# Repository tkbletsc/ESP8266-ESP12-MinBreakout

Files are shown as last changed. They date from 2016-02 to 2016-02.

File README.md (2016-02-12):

# ESP8266-ESP12-MinBreakout
Minimal breakout board for the ESP8266 model ESP12 board

A breakout board for the ESP8266 model ESP12 board, but with a twist. The down-facing header pins are installed with very little protrusion on the top, then some insulation is added (electrical tape), then the ESP12 is SMT soldered on top. This makes this breakout far smaller than the existing ones, and much more breadboard friendly.

Comes in through-hole and SMT flavors. The through-hole flavor rev1 has been successfully fabbed and populated and works perfectly.

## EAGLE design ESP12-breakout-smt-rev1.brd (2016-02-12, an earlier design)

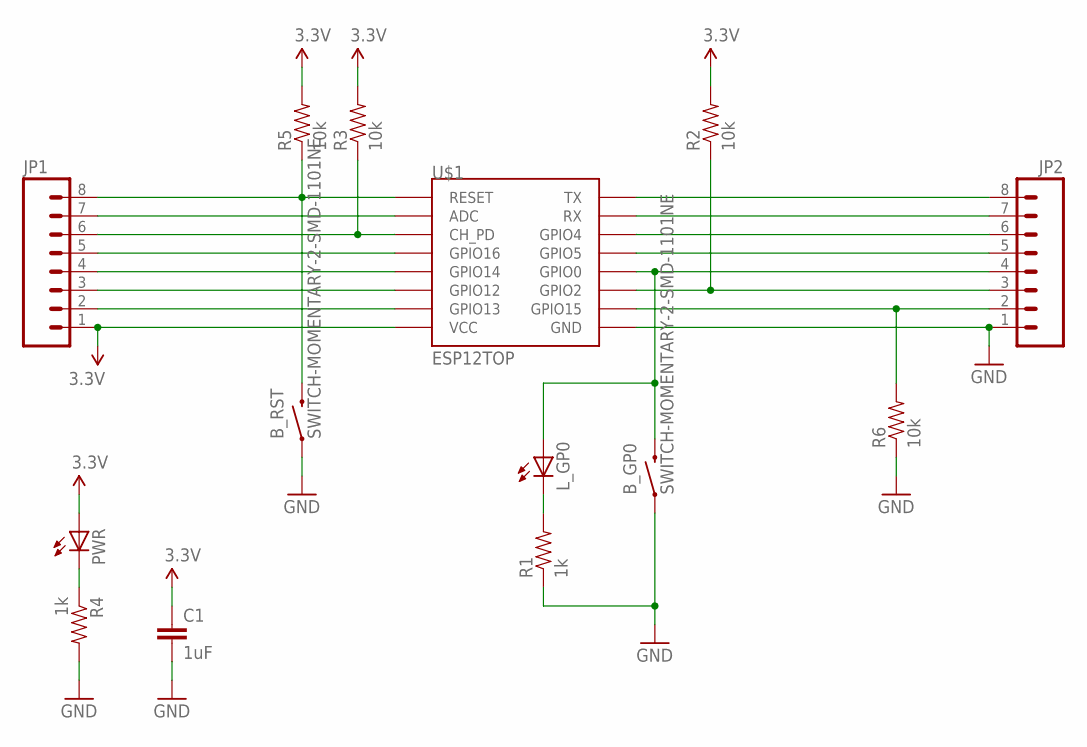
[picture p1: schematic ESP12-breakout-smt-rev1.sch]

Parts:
B_GP0: SWITCH-MOMENTARY-2-SMD-1101NE; TACTILE-SWITCH-1101NE
B_RST: SWITCH-MOMENTARY-2-SMD-1101NE; TACTILE-SWITCH-1101NE
C1: 1uF; 0805
JP1, JP2: M08; 1X08_PIN1_NO_SILK
L_GP0: LEDCHIPLED_0805; CHIPLED_0805
PWR: LEDCHIPLED_0805; CHIPLED_0805
R1, R4: 1k; 0603-RES
R2, R3, R5, R6: 10k; 0603-RES
U$1: ESP12TOP

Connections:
3.3V: C1.1, JP1.1, PWR.A, R2.2, R3.2, R5.2, U$1.VCC
GND: B_GP0.1, B_RST.1, C1.2, JP2.1, R1.1, R4.2, R6.1, U$1.GND
unnamed: L_GP0.C, R1.2
unnamed: JP1.2, U$1.GPIO13
unnamed: JP1.3, U$1.GPIO12
unnamed: JP1.4, U$1.GPIO14
unnamed: JP1.5, U$1.GPIO16
unnamed: JP1.6, R3.1, U$1.CH_PD
unnamed: JP1.7, U$1.ADC
unnamed: B_RST.2, JP1.8, R5.1, U$1.RESET
unnamed: PWR.C, R4.1
unnamed: JP2.2, R6.2, U$1.GPIO15
unnamed: JP2.3, R2.1, U$1.GPIO2
unnamed: B_GP0.2, JP2.4, L_GP0.A, U$1.GPIO0
unnamed: JP2.5, U$1.GPIO5
unnamed: JP2.6, U$1.GPIO4
unnamed: JP2.7, U$1.RXD (RX)
unnamed: JP2.8, U$1.TXD (TX)

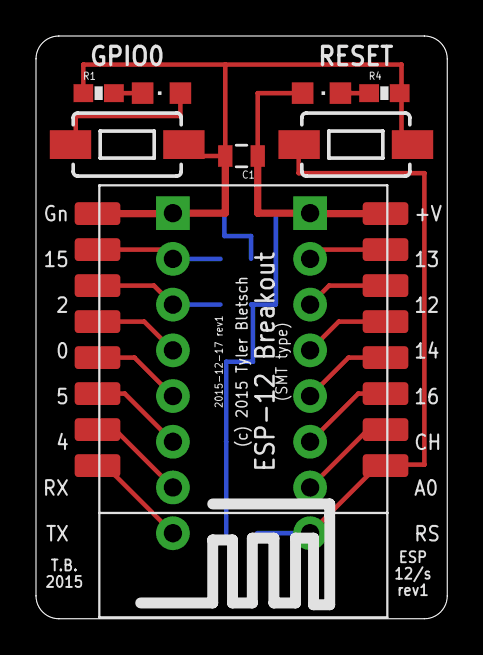
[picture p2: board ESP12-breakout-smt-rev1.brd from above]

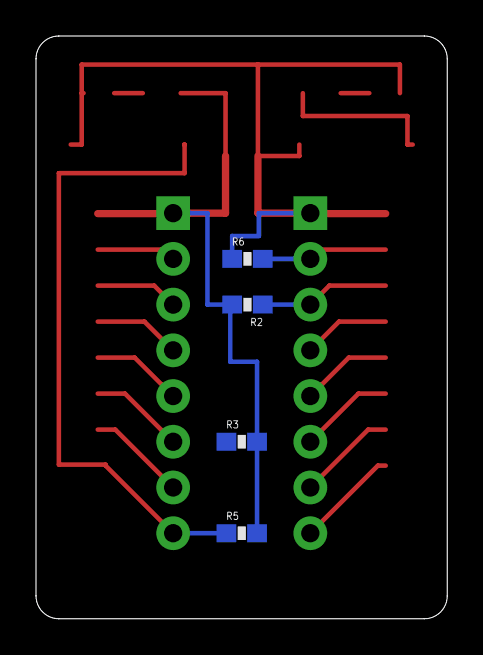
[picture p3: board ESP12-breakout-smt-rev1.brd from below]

Board: 2 copper layers, 22.8 x 32.4 mm, 14 parts (4 on the bottom side), 18 nets.

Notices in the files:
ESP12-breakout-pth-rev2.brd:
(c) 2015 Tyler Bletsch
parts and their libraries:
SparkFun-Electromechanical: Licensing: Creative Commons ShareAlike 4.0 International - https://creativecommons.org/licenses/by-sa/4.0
